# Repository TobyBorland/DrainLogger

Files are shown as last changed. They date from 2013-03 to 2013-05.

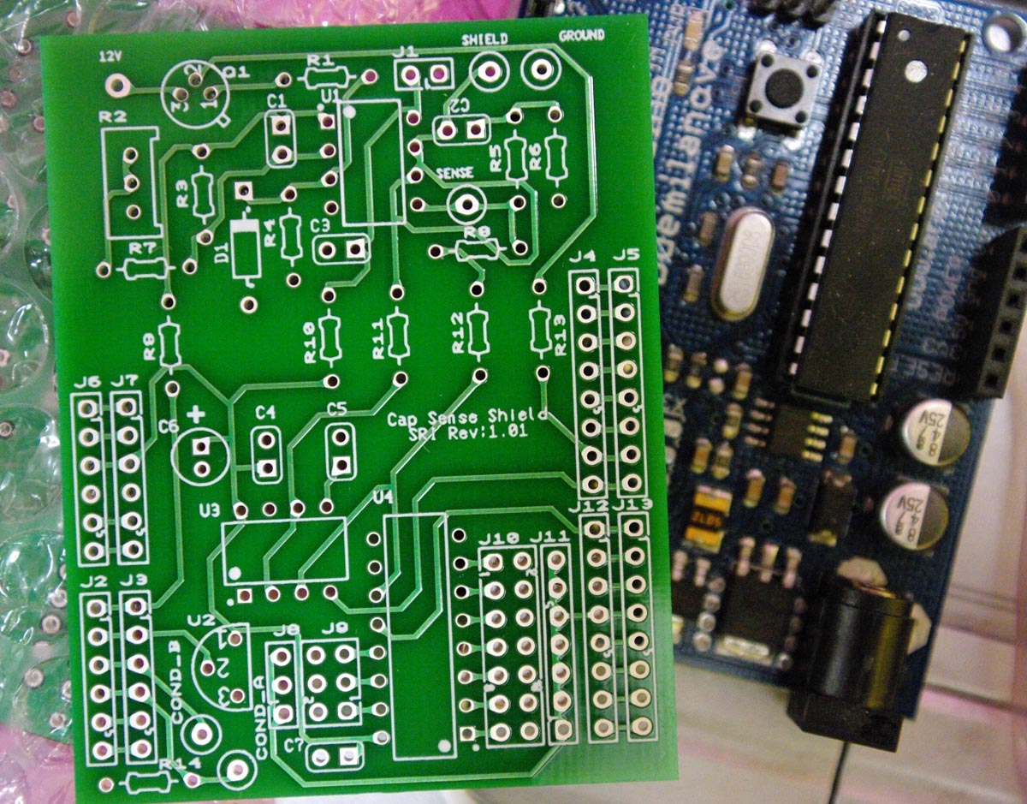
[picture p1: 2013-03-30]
Cap_Shield_07_Gerber_RS274X/Cap_Shield_07.jpg

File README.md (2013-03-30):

DrainLogger
===========

Production code for capacitance based water level sensing on Arduino platform FEB2013

The circuit uses a LadyAda SD/RTC board and a custom high sensitivity capacitance sensing board (Cap_Shield_07*.*)
Included are Gerber design files for a Solar power regulator that float charges a SLA 1500mAh battery and supplies power to the circuit (Solar_SLA_PSU_02*.*).
The Arduino circuit has been redeveloped for micro-power consumption, the shields are switched off via a power MOSFET and the processor set to hibernate.
The MOSFET is driven by a totem pole NPN/PNP switch, a Xino Arduino clone board with prototyping space is used.

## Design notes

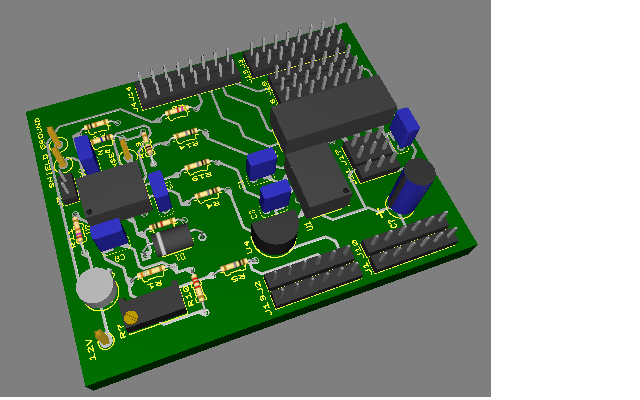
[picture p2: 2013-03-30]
Cap_Shield_07_Gerber_RS274X/3D capshield NOV12.bmp

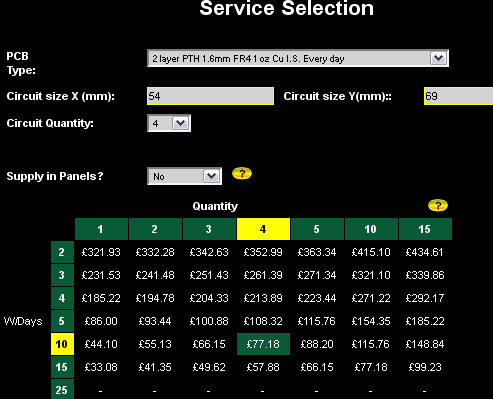
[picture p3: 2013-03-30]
Cap_Shield_07_Gerber_RS274X/PCB_train_Cap_Shield.png

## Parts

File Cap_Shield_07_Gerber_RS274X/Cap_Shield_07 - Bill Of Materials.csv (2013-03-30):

Ultiboard Information Export File
Design Name : Cap_Shield_07 - Bill Of Materials
Report Date : 15 November 2012
Report Time : 23:11
--------------------------------------------------------------------------------
VALUE | SHAPE | # | REFDES | DEVICE
0.01uF | CAPR250-500X250X550 | 1 | C5 | CAPACITOR_VIRTUAL
0.1uF | CAPR250-500X250X550 | 4 | C2,C3,C4,C7 | CAPACITOR_VIRTUAL
0.1Ohm | R0204R7_5 | 4 | R9,R10,R11,R12 | RESISTOR_VIRTUAL
1MOhm | R0204R7_5 | 1 | R8 | RESISTOR_VIRTUAL
1N5248B | DO-35 | 1 | D1 | 1N5248B
1kOhm | R0204R7_5 | 1 | R4 | RESISTOR_VIRTUAL
2N2222A | TO18 | 1 | Q1 | 2N2222A
4.7kOhm | R0204R7_5 | 1 | R13 | RESISTOR_VIRTUAL
4.7nF | CAPR250-500X250X550 | 1 | C1 | CAPACITOR_VIRTUAL
10MOhm | R0204R7_5 | 1 | R5 | RESISTOR_VIRTUAL
10kOhm | R0204R7_5 | 2 | R6,R14 | RESISTOR_VIRTUAL
20kOhm | TRIM-3386W | 1 | R2 | POTENTIOMETER_VIRTUAL
27kOhm | R0204R7_5 | 1 | R1 | RESISTOR_VIRTUAL
39kOhm | R0204R7_5 | 1 | R3 | RESISTOR_VIRTUAL
47uF | CAPPR200-500X1100 | 1 | C6 | CAP_ELECTROLIT_VIRTUAL
2200Ohm | R0204R7_5 | 1 | R7 | RESISTOR_VIRTUAL
4060BD_5V | DIP16300 | 1 | U4 | 4060BD_5V
HDR1X2 | HDR1X2 | 1 | J1 | HDR1X2
HDR1X3 | HDR1X3 | 1 | J8 | HDR1X3
HDR1X6 | HDR1X6 | 4 | J2,J3,J6,J7 | HDR1X6
HDR1X7 | HDR1X7 | 1 | J11 | HDR1X7
HDR1X8 | HDR1X8 | 4 | J4,J5,J12,J13 | HDR1X8
HDR2X3 | HDR2X3 | 1 | J9 | HDR2X3
HDR2X7 | HDR2X7 | 1 | J10 | HDR2X7
LMC555CH | DIP8300 | 1 | U3 | LMC555CH
LMC6482 | DIP8300 | 1 | U1 | LMC6482
TEST_PT1 | PB | 5 | COND_A,COND_B,GROUND,SENSE,SHIELD | TEST_PT1
TEST_PT2 | PIN | 1 | 12V | TEST_PT2
TMP36 | TO5 | 1 | U2 | TMP36

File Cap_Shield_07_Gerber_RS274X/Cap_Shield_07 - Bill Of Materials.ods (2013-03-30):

Ultiboard Information Export File
Design Name : Cap_Shield_07 - Bill Of Materials
Report Date : 15 November 2012
Report Time : 23:11
--------------------------------------------------------------------------------
VALUE | SHAPE | # | REFDES | DEVICE | Manufacturer | Manufacturer Reference | RS Stock | Price less VAT | Toby Price less VAT | Min quantity | Min required | Order Requirement | Toby sum price | Sum price | Non RS notes
0.01uF | CAPR250-500X250X550 | 1 | C5 | CAPACITOR_VIRTUAL | Murata (http://uk.rs-online.com/web/c/?searchTerm=Murata&searchType=Brand) | RPER72A103K2M1A03A | 653-0260 | £0.25 | £0.20 | 25 | 4 | 25 | £6.35 | £5.08
0.1uF | CAPR250-500X250X550 | 4 | C2,C3,C4,C7 | CAPACITOR_VIRTUAL | Murata (http://uk.rs-online.com/web/c/?searchTerm=Murata&searchType=Brand) | RPEF51H104Z2M1A03A | 721-5240 | £0.06 | £0.05 | 50 | 16 | 50 | £3.15 | £2.50
0.1Ohm | R0204R7_5 | 4 | R9,R10,R11,R12 | RESISTOR_VIRTUAL |  |  |  |  |  |  | 0 | 0 | 0 | 0
1MOhm | R0204R7_5 | 1 | R8 | RESISTOR_VIRTUAL | Arcol (http://uk.rs-online.com/web/c/?searchTerm=Arcol&searchType=Brand) | MRA02071MBTA015 | 487-8813 | £0.84 | £0.67 | 5 | 4 | 5 | £3.37 | £3.37
ZENER | DO-35 | 1 | D1 | 5.1v Zener Diode | ON Semiconductor (http://uk.rs-online.com/web/c/?searchTerm=ON+Semiconductor&searchType=Brand) | 1N5338BRLG | 625-6451 | £0.25 | £0.20 | 5 | 4 | 5 | £1.00 | £1.00
1kOhm | R0204R7_5 | 1 | R4 | RESISTOR_VIRTUAL | RS (http://uk.rs-online.com/web/c/?searchTerm=RS&searchType=Brand) |  | 707-7666 | £0.02 | £0.01 | 10 | 4 | 10 | £0.12 | £0.12
2N2222A | TO18 | 1 | Q1 | 2N2222A | Magnatec (http://uk.rs-online.com/web/c/?searchTerm=Magnatec&searchType=Brand) | 2N2222A | 295-028 | £0.58 | £0.46 | 5 | 4 | 5 | £2.32 | £2.32
4.7kOhm | R0204R7_5 | 1 | R13 | RESISTOR_VIRTUAL | RS (http://uk.rs-online.com/web/c/?searchTerm=RS&searchType=Brand) |  | 707-7726 | £0.02 | £0.01 | 10 | 4 | 10 | £0.15 | £0.12
4.7nF | CAPR250-500X250X550 | 1 | C1 | CAPACITOR_VIRTUAL | Murata (http://uk.rs-online.com/web/c/?searchTerm=Murata&searchType=Brand) | RDER72E472K2K1A11B | 749-2181 | £0.23 | £0.18 | 5 | 4 | 5 | £1.15 | £0.92
10MOhm | R0204R7_5 | 1 | R5 | RESISTOR_VIRTUAL | TE Connectivity (http://uk.rs-online.com/web/c/?searchTerm=TE+Connectivity&searchType=Brand) | CFR25J10M | 135-667 | £0.02 | £0.01 | 10 | 4 | 10 | £0.18 | £0.14
10kOhm | R0204R7_5 | 2 | R6,R14 | RESISTOR_VIRTUAL | RS (http://uk.rs-online.com/web/c/?searchTerm=RS&searchType=Brand) |  | 707-7745 | £0.01 | £0.01 | 10 | 4 | 10 | £0.09 | £0.09
20kOhm | TRIM-3386W | 1 | R2 | POTENTIOMETER_VIRTUAL | Bourns (http://uk.rs-online.com/web/c/?searchTerm=Bourns&searchType=Brand) | 3299W-1-203LF | 522-0350 | £1.39 | £1.11 | 1 | 4 | 4 | £5.56 | £4.45
27kOhm | R0204R7_5 | 1 | R1 | RESISTOR_VIRTUAL | RS (http://uk.rs-online.com/web/c/?searchTerm=RS&searchType=Brand) |  | 707-7782 | £0.01 | £0.01 | 10 | 4 | 10 | £0.11 | £0.09
39kOhm | R0204R7_5 | 1 | R3 | RESISTOR_VIRTUAL | RS (http://uk.rs-online.com/web/c/?searchTerm=RS&searchType=Brand) |  | 707-7791 | £0.01 | £0.01 | 10 | 4 | 10 | £0.11 | £0.09
47uF | CAPPR200-500X1100 | 1 | C6 | CAP_ELECTROLIT_VIRTUAL | RS (http://uk.rs-online.com/web/c/?searchTerm=RS&searchType=Brand) |  | 711-1444 | £0.04 | £0.04 | 50 | 4 | 50 | £1.75 | £1.75
2200Ohm | R0204R7_5 | 1 | R7 | RESISTOR_VIRTUAL | RS (http://uk.rs-online.com/web/c/?searchTerm=RS&searchType=Brand) |  | 707-7690 | £0.02 | £0.01 | 10 | 4 | 10 | £0.15 | £0.12
4060BD_5V | DIP16300 | 1 | U4 | 4060BD_5V | STMicroelectronics (http://uk.rs-online.com/web/c/?searchTerm=STMicroelectronics&searchType=Brand) | HCF4060BEY | 714-0562P | £0.16 | £0.14 | 20 | 0 | 20 | £2.78 | £2.78
HDR1X2 | HDR1X2 | 1 | J1 | HDR1X2 |  |  |  |  |  |  |  | 0 | 0 | 0
HDR1X3 | HDR1X3 | 1 | J8 | HDR1X3 |  |  |  |  |  |  |  | 0 | 0 | 0
HDR1X6 | HDR1X6 | 2 | J2,J3,J6,J7 | HDR1X6 |  |  |  |  |  |  |  | 0 | 0 | 0
HDR1X7 | HDR1X7 | 1 | J11 | HDR1X7 |  |  |  |  |  |  |  | 0 | 0 | 0
HDR1X8 | HDR1X8 | 2 | J4,J5,J12,J13 | HDR1X8 |  |  |  |  |  |  |  | 0 | 0 | 0
HDR2X3 | HDR2X3 | 1 | J9 | HDR2X3 |  |  |  |  |  |  |  | 0 | 0 | 0
HDR2X7 | HDR2X7 | 1 | J10 | HDR2X7 |  |  |  |  |  |  |  | 0 | 0 | 0
LMC555CH | DIP8300 | 1 | U3 | LMC555CH | Texas Instruments (http://uk.rs-online.com/web/c/?searchTerm=Texas+Instruments&searchType=Brand) | LMC555CN/NOPB | 534-4002 | £0.85 | £0.68 | 1 | 4 | 4 | £2.72 | £3.40
LMC6482 | DIP8300 | 1 | U1 | LMC6482 | Texas Instruments (http://uk.rs-online.com/web/c/?searchTerm=Texas+Instruments&searchType=Brand) | LMC6482AIN/NOPB | 536-0183 | £1.56 | £1.25 | 5 | 4 | 5 | £6.23 | £7.78
TEST_PT1 | PB | 5 | COND_A,COND_B,GROUND,SENSE,SHIELD | TEST_PT1 |  |  |  |  |  |  |  | 0 | 0 | 0
TEST_PT2 | PIN | 1 | 12V | TEST_PT2 |  |  |  |  |  |  |  | 0 | 0 | 0
TMP36 | TO5 | 1 | U2 | TMP36 | Analog Devices (http://uk.rs-online.com/web/c/?searchTerm=Analog+Devices&searchType=Brand) | TMP36GT9Z | 427-351 | £1.39 | £1.11 | 5 | 4 | 5 | £5.56 | £6.95
 |  |  |  |  |  |  |  |  |  |  |  | 0 | 0 | 0
Socket strip | HDR1x6 | 2 |  |  | Winslow (http://uk.rs-online.com/web/c/?searchTerm=Winslow&searchType=Brand) |  | 401-699 | £1.50 | £1.20 | 5 | 8 | 10 | £15.02 | £12.02
Socket strip | HDR1x8 | 2 |  |  | Winslow (http://uk.rs-online.com/web/c/?searchTerm=Winslow&searchType=Brand) |  |  |  |  |  |  | 0 | 0 | 0
Silicone conformal coating |  |  |  |  | RS (http://uk.rs-online.com/web/c/?searchTerm=RS&searchType=Brand) |  | 494-714 | £9.02 | £7.22 | 1 | 1 | 1 | £9.02 | £7.22
Flux remover |  |  |  |  | ITW Chemtronics (http://uk.rs-online.com/web/c/?searchTerm=ITW+Chemtronics&searchType=Brand) | ES830BE | 298-7937 | £7.64 | £6.11 | 1 | 1 | 1 | £7.64 | £6.11
Board rinse |  |  |  |  | RS (http://uk.rs-online.com/web/c/?searchTerm=RS&searchType=Brand) |  | 497-016 | £6.90 | £5.52 | 1 | 1 | 1 | £6.90 | £5.52
 |  |  |  |  |  |  |  |  |  |  |  | 0 | 0 | 0
CoAx cable |  |  |  |  |  | Cricklewood | ZS1 | £0.40 |  | 1 | 4 | 4 | £1.60 | 0 | http://www.cricklewoodelectronics.com/Cricklewood/product.php?productid=18957&cat=326&page=1
 |  |  |  |  |  |  |  |  |  |  |  | 0 | 0 | 0
INA125PA | DIP16300 | 1 | U47 | OP_AMP | Texas Instruments (http://uk.rs-online.com/web/c/?searchTerm=Texas+Instruments&searchType=Brand) | INA125PA | 252-1593 | £4.39 | £3.51 | 1 | 2 | 2 | £7.02 | £8.78
Optocoupler | DIP8300 | 1 | U39 | ACPL-827-000E | Avago Technologies (http://uk.rs-online.com/web/c/?searchTerm=Avago+Technologies&searchType=Brand) | ACPL-827-000E | 693-5937 | £0.63 | £0.50 | 1 | 2 | 2 | £1.26 | £1.01
Piezodisc |  |  |  |  | RS (http://uk.rs-online.com/web/c/?searchTerm=RS&searchType=Brand) |  | 724-3162 | £0.34 | £0.27 | 5 | 1 | 5 | £1.70 | £1.36
Optocoupler | DIP8300 | 1 | U39a | H11A1X | Isocom (http://uk.rs-online.com/web/c/?searchTerm=Isocom&searchType=Brand) | H11A1X | 111-122 | £0.49 | £0.39 | 1 | 1 | 1 | £0.49 | £0.39
 |  |  |  |  |  |  |  |  |  |  |  | 0 | 0 | 0
 |  |  |  |  |  |  |  |  |  |  |  | 0 | 0 | 0
 |  |  |  |  |  |  |  |  |  |  |  | 0 | 0 | 0
Ultiboard Information Export File |  |  |  |  |  |  |  |  |  |  |  | 0 | 0 | 0
 |  |  |  |  |  |  |  |  |  |  |  | 0 | 0 | 0
Design Name : drainlogger_PSU(drainlogger_PSU) - Bill Of Materials |  |  |  |  |  |  |  |  |  |  |  | 0 | 0 | 0
Report Date : 16 November 2012 |  |  |  |  |  |  |  |  |  |  |  | 0 | 0 | 0
Report Time : 01:05 |  |  |  |  |  |  |  |  |  |  |  | 0 | 0 | 0
-------------------------------------------------------------------------------- |  |  |  |  |  |  |  |  |  |  |  | 0 | 0 | 0
 |  |  |  |  |  |  |  |  |  |  |  | 0 | 0 | 0
VALUE | SHAPE | # | REFDES | DEVICE |  |  |  |  |  |  |  | 0 | 0 | 0
 |  |  |  |  |  |  |  |  |  |  |  | 0 | 0 | 0
0.27Ohm | RES12 | 1 | R3 | RESISTOR_VIRTUAL |  |  | N/A |  |  |  |  | 0 | 0 | 0
0.68Ohm | RES12 | 1 | R2 | RESISTOR_VIRTUAL |  |  | N/A |  |  |  |  | 0 | 0 | 0
1.5kOhm | R0204R7_5 | 1 | R7 | RESISTOR_VIRTUAL | RS (http://uk.rs-online.com/web/c/?searchTerm=RS&searchType=Brand) |  | 707-7681 | £0.02 | £0.01 | 10 | 4 | 10 | £0.15 | £0.12
1N5818 | DO-41 | 1 | D1 | 1N5818/9 | ON Semiconductor (http://uk.rs-online.com/web/c/?searchTerm=ON+Semiconductor&searchType=Brand) | 1N5818RLG | 625-5212 | £0.46 | £0.37 | 1 | 4 | 4 | £1.84 | £1.47
1Ohm | RES12 | 1 | R1 | RESISTOR_VIRTUAL | RS (http://uk.rs-online.com/web/c/?searchTerm=RS&searchType=Brand) |  | 707-7981 | £0.03 | £0.02 | 10 | 4 | 10 | £0.27 | £0.22
4.7kOhm | NTC_K164 | 1 | R4 | RESISTOR_VIRTUAL | BC Components (http://uk.rs-online.com/web/c/?searchTerm=BC+Components&searchType=Brand) | 238164066473 | 538-0749 | £0.61 | £0.49 | 1 | 4 | 4 | £2.42 | £1.94 | Maplin:FX21X
200mA | PTC_B77 | 1 | R8 | RESETTABLE FUSE | TE Connectivity (http://uk.rs-online.com/web/c/?searchTerm=TE+Connectivity&searchType=Brand) | RXEF010 | 517-6562 | £0.31 | £0.25 | 10 | 4 | 10 | £3.10 | £2.48
10kOhm | TRIM-3386W | 1 | R6 | POTENTIOMETER_VIRTUAL | Murata (http://uk.rs-online.com/web/c/?searchTerm=Murata&searchType=Brand) | PV36X103C01B00 | 725-0325 | £0.95 | £0.76 | 1 | 4 | 4 | £3.80 | £3.04
10nF | CAPR250-500X250X550 | 1 | C1 | CAPACITOR_VIRTUAL | Murata (http://uk.rs-online.com/web/c/?searchTerm=Murata&searchType=Brand) | RPER72A103K2M1A03A | 653-0260 | £0.25 | £0.20 | 25 | 4 | 25 | £5.08 | £6.35
100uF | CAPR250-500X250X550 | 2 | C2,C3 | CAPACITOR_VIRTUAL | Vishay (http://uk.rs-online.com/web/c/?searchTerm=Vishay&searchType=Brand) | MAL203851101E3 | 684-2018 | £0.12 | £0.09 | 5 | 8 | 10 | £1.16 | £0.93
100Ohm | R0204R7_5 | 1 | R5 | RESISTOR_VIRTUAL | RS (http://uk.rs-online.com/web/c/?searchTerm=RS&searchType=Brand) |  | 707-7587 | £0.02 | £0.01 | 10 | 4 | 10 | £0.15 | £0.12
2200uF | CAPPR750-1800X3550 | 1 | C4 | CAP_ELECTROLIT_VIRTUAL | Vishay (http://uk.rs-online.com/web/c/?searchTerm=Vishay&searchType=Brand) | MAL203850222E3 | 684-1992 | £0.78 | £0.63 | 5 | 4 | 5 | £3.91 | £3.13
HDR1X2 | SMK2R5MIL_A | 3 | J1,J2,J3 | HDR1X2 | Phoenix Contact (http://uk.rs-online.com/web/c/?searchTerm=Phoenix+Contact&searchType=Brand) | SMKDSN 1,5/ 2-5,08 | 206-4595 | £0.48 | £0.38 | 5 | 12 | 15 | £7.20 | £5.76
5V DC-DC | TRIM-3299W | 1 | U1 | R-785.0-0.5 | Recom (http://uk.rs-online.com/web/c/?searchTerm=Recom&searchType=Brand) | R-785.0-0.5 | 532-8050P | £5.48 | £4.66 | 1 | 4 | 4 | £21.92 | £18.63
L200CV | TO-220(TO5B) | 1 | L200C1 | Pentawatt | STMicroelectronics | Cricklewood | N/A | £1.50 | £1.50 | 1 | 4 | 4 | £6.00 | £6.00
Heatsink |  |  |  |  | AAVID THERMALLOY (http://uk.rs-online.com/web/c/?searchTerm=AAVID+THERMALLOY&searchType=Brand) | 574502B00000G | 712-4197 | £0.27 | £0.22 | 5 | 4 | 5 | £1.35 | £1.08
1.6Ohm (+nichrome link) | 0.5W |  | R1, R2, R2 |  | RS (http://uk.rs-online.com/web/c/?searchTerm=RS&searchType=Brand) |  | 707-8003 | £0.02 | £0.02 | 10 | 4 | 10 | £0.20 | £0.16
Battery cable |  |  |  |  |  | Cricklewood | ZL27H | £19.00 | £19.00 | 1 | 1 | 1 | £19.00 | £19.00 | http://www.cricklewoodelectronics.com/Cricklewood/product.php?productid=18931&cat=322&page=1
Spade Connectors |  |  |  |  | JST (http://uk.rs-online.com/web/c/?searchTerm=JST&searchType=Brand) | 4803-187 | 688-1022 | £0.02 | £0.02 | 100 | 8 | 100 | £2.30 | £1.80
Batterybox |  |  |  |  | Gunther Spelsberg (http://uk.rs-online.com/web/c/?searchTerm=Gunther+Spelsberg&searchType=Brand) | 11040401 | 220-428 | £6.65 | £5.32 | 1 | 4 | 4 | £26.60 | £21.28
Battery box grommet |  |  |  |  | RS (http://uk.rs-online.com/web/c/?searchTerm=RS&searchType=Brand) |  | 444-2616 | £0.51 | £0.41 | 5 | 4 | 5 | £2.56 | £2.05
12V Battery |  |  |  |  | Yuasa (http://uk.rs-online.com/web/c/?searchTerm=Yuasa&searchType=Brand) | Y 1.2-12 FR | 614-1905 | £9.56 | £7.65 | 1 | 4 | 4 | £38.24 | £30.59
 |  |  |  |  |  |  |  |  |  |  |  |  | £240.75 | £211.63
TOTAL+VAT |  |  |  |  |  |  |  |  |  |  |  |  | £288.90 | £253.95

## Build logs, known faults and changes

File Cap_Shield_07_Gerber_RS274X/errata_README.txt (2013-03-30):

Errors and addendums in production board:

1: U2 silkscreen is reversed, temperature sensor faces other way around
2: Battery sense circuit revised to NPN/PNP totem switch

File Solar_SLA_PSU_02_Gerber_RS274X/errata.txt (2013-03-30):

1N456A diode replaced with low leakage diode

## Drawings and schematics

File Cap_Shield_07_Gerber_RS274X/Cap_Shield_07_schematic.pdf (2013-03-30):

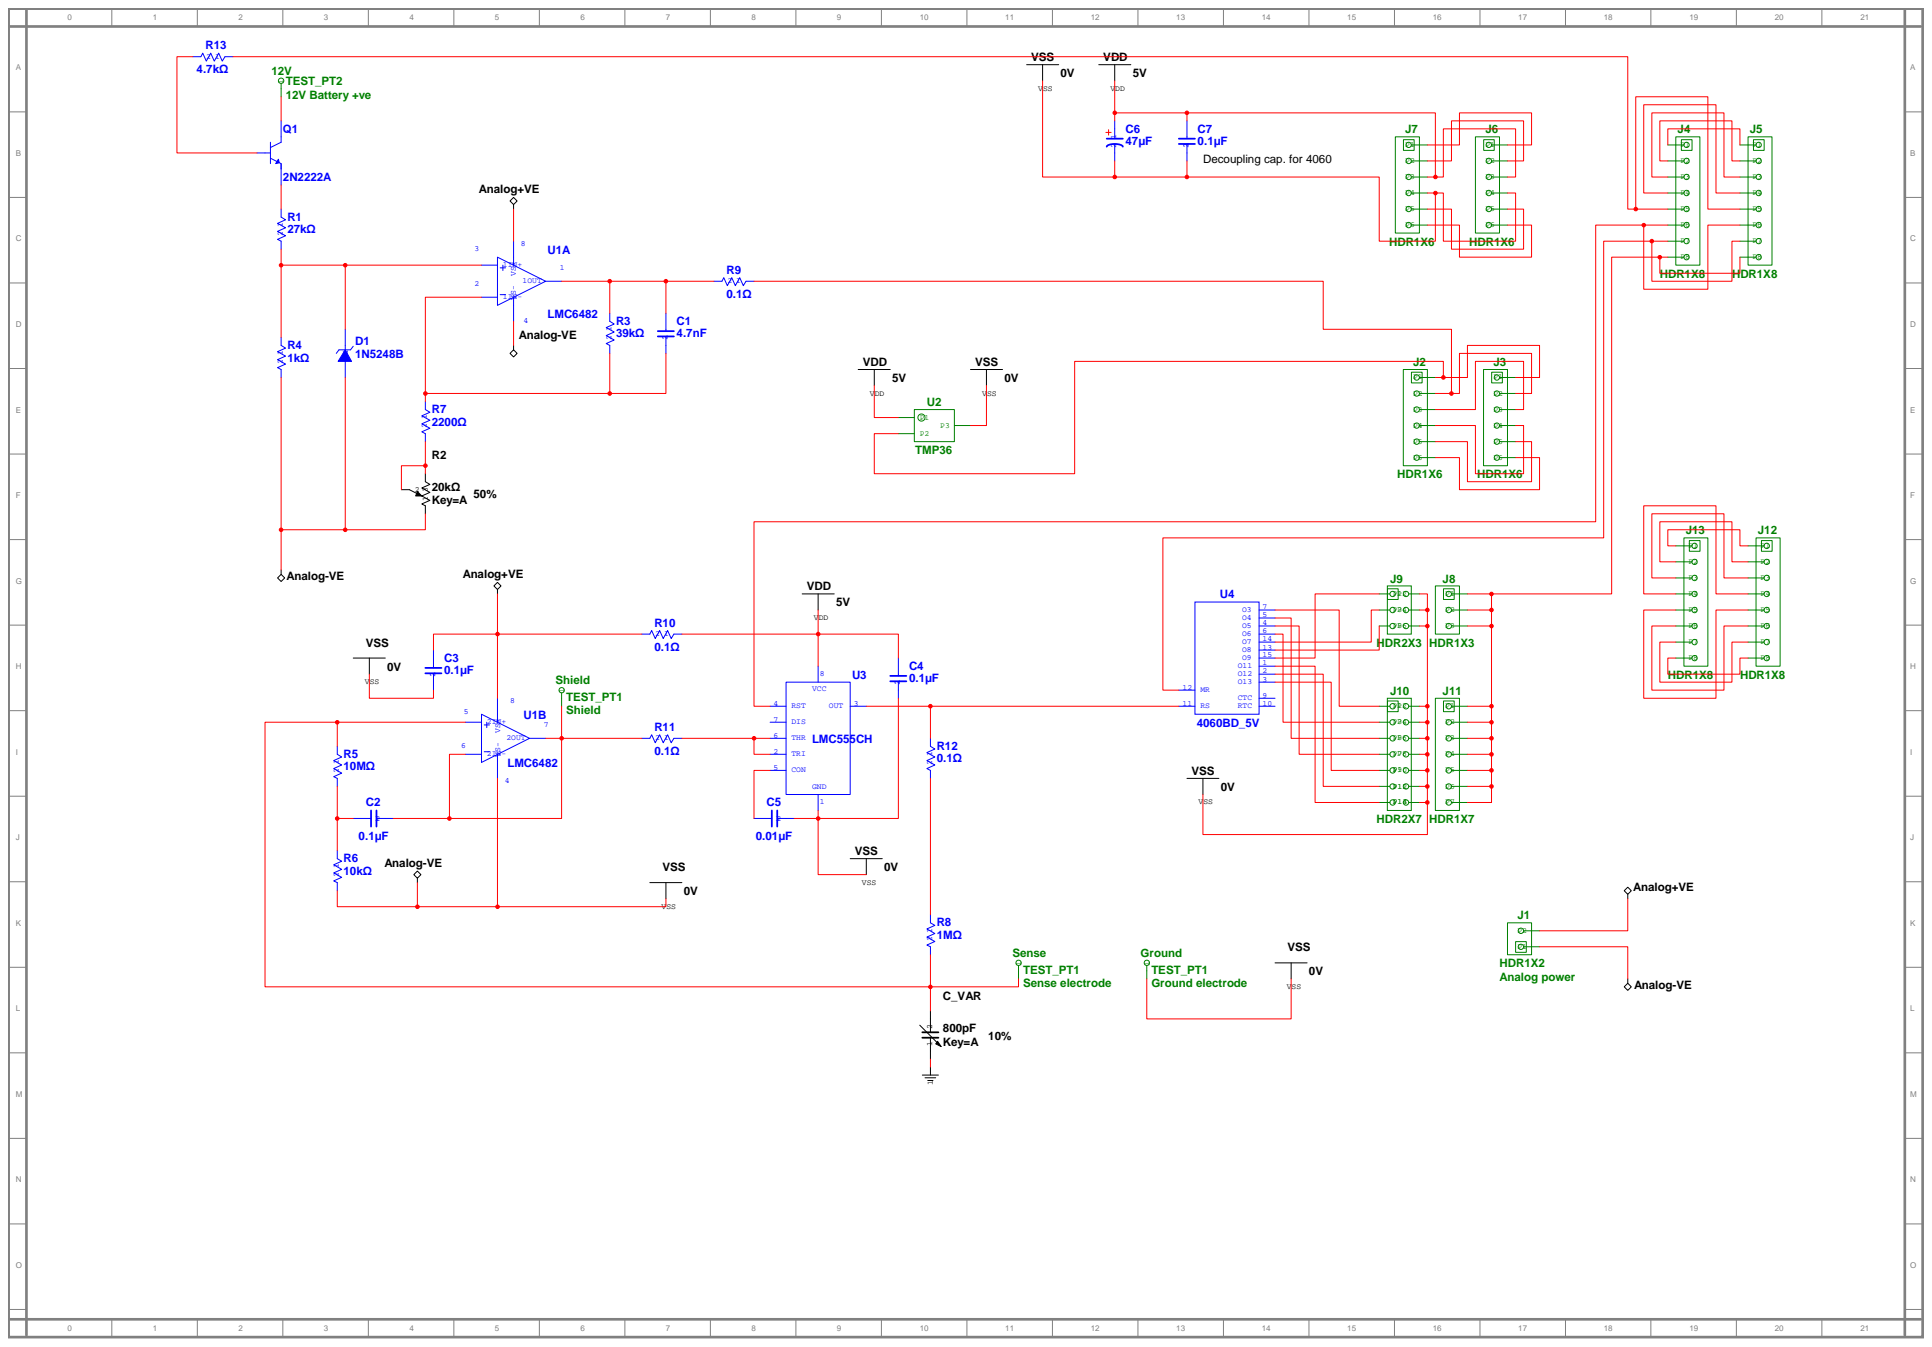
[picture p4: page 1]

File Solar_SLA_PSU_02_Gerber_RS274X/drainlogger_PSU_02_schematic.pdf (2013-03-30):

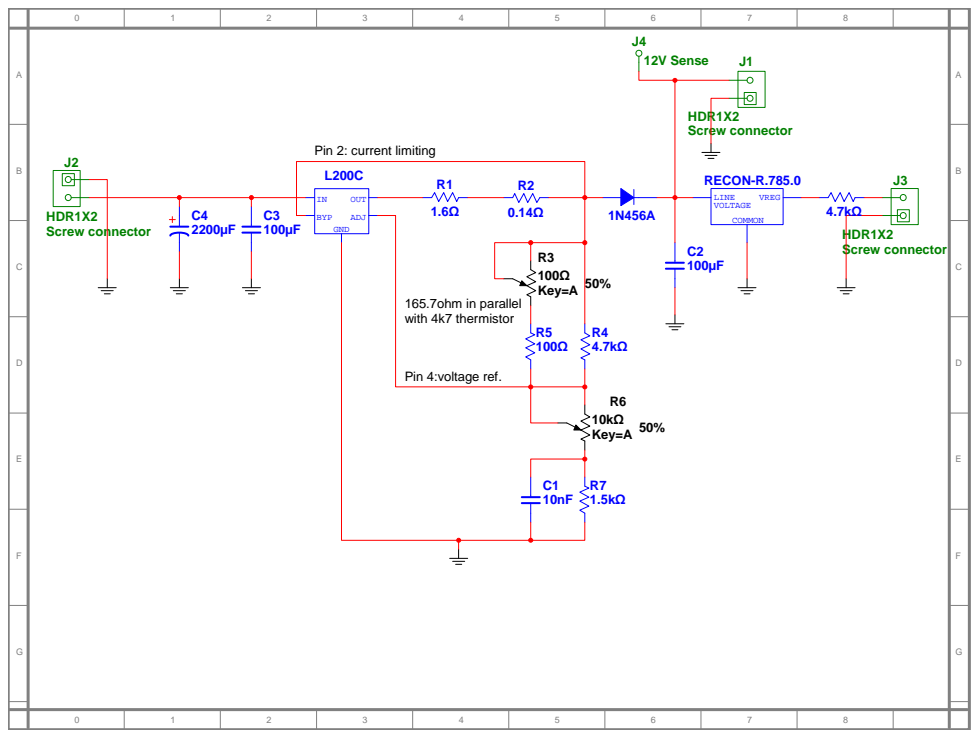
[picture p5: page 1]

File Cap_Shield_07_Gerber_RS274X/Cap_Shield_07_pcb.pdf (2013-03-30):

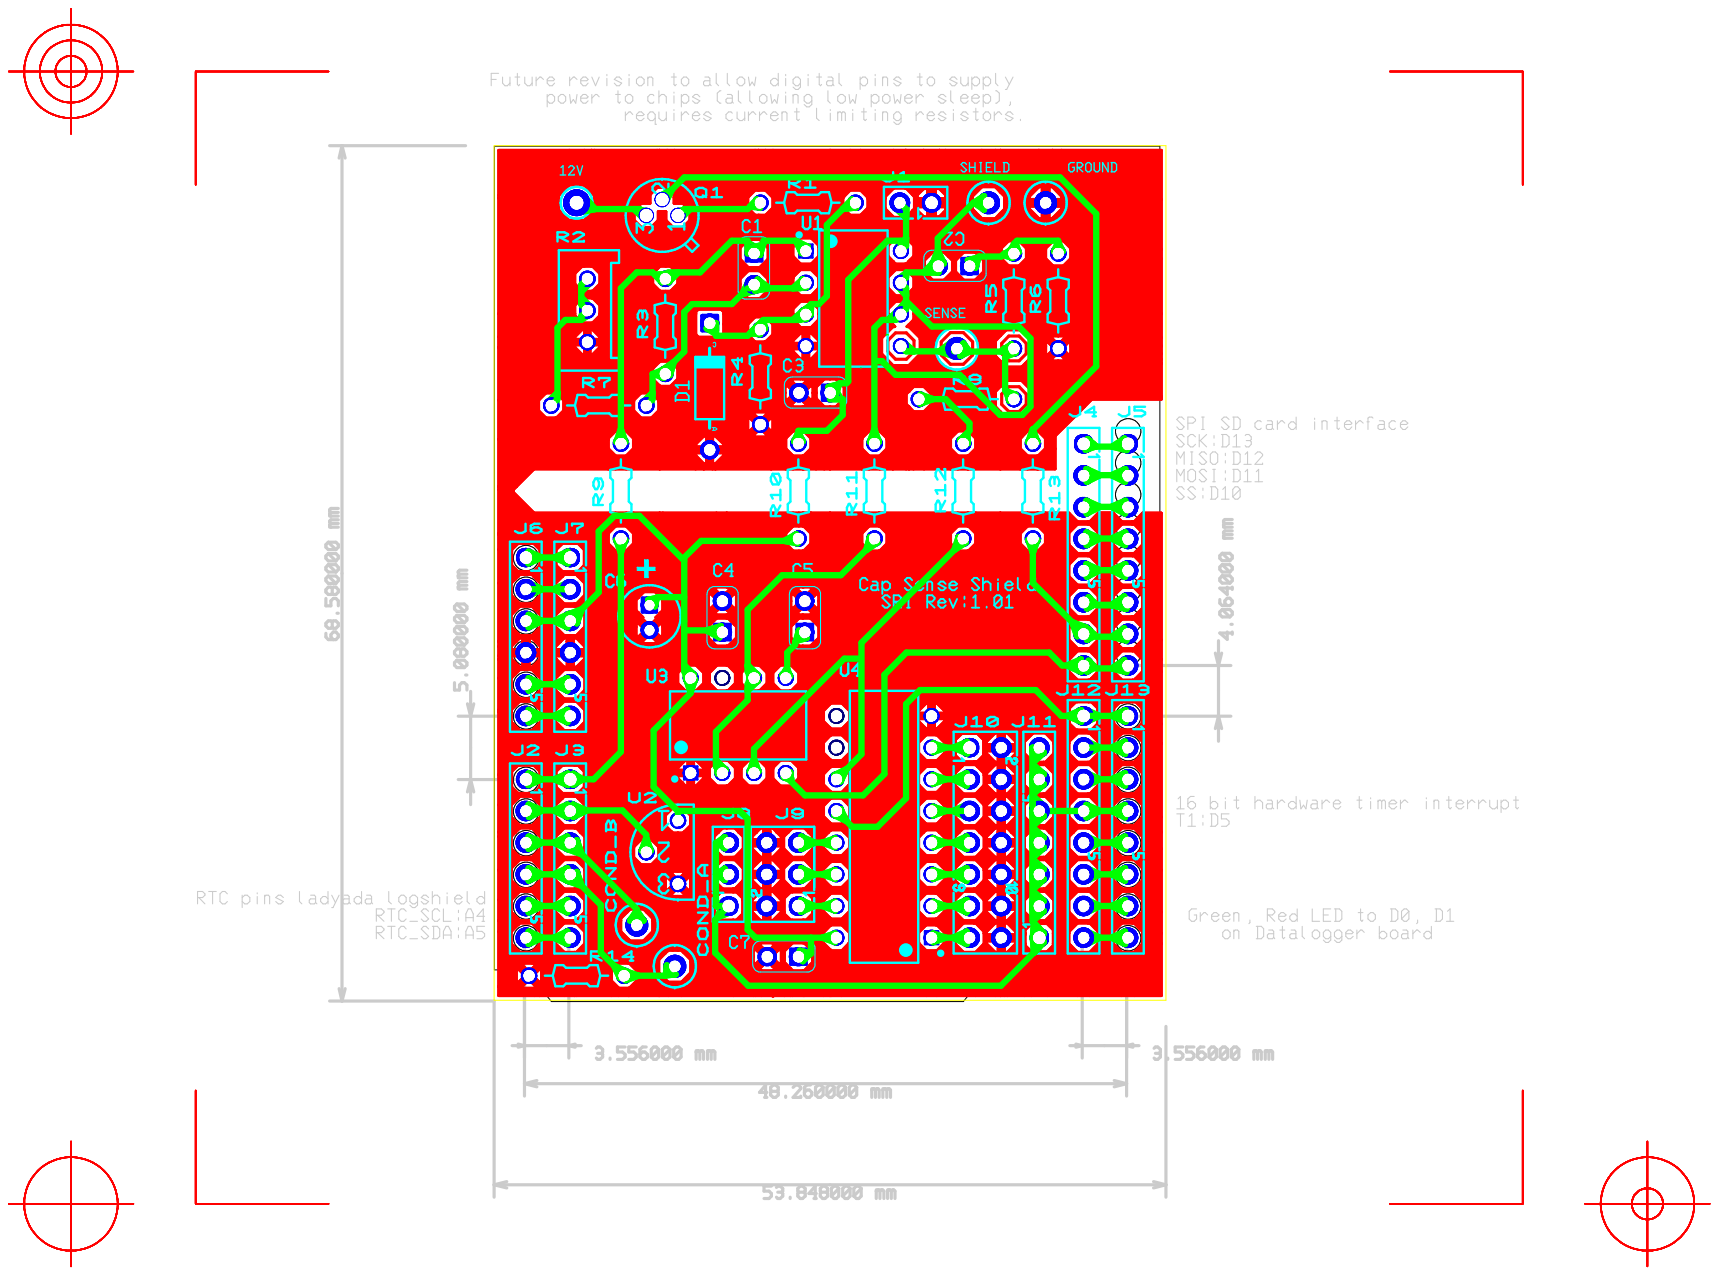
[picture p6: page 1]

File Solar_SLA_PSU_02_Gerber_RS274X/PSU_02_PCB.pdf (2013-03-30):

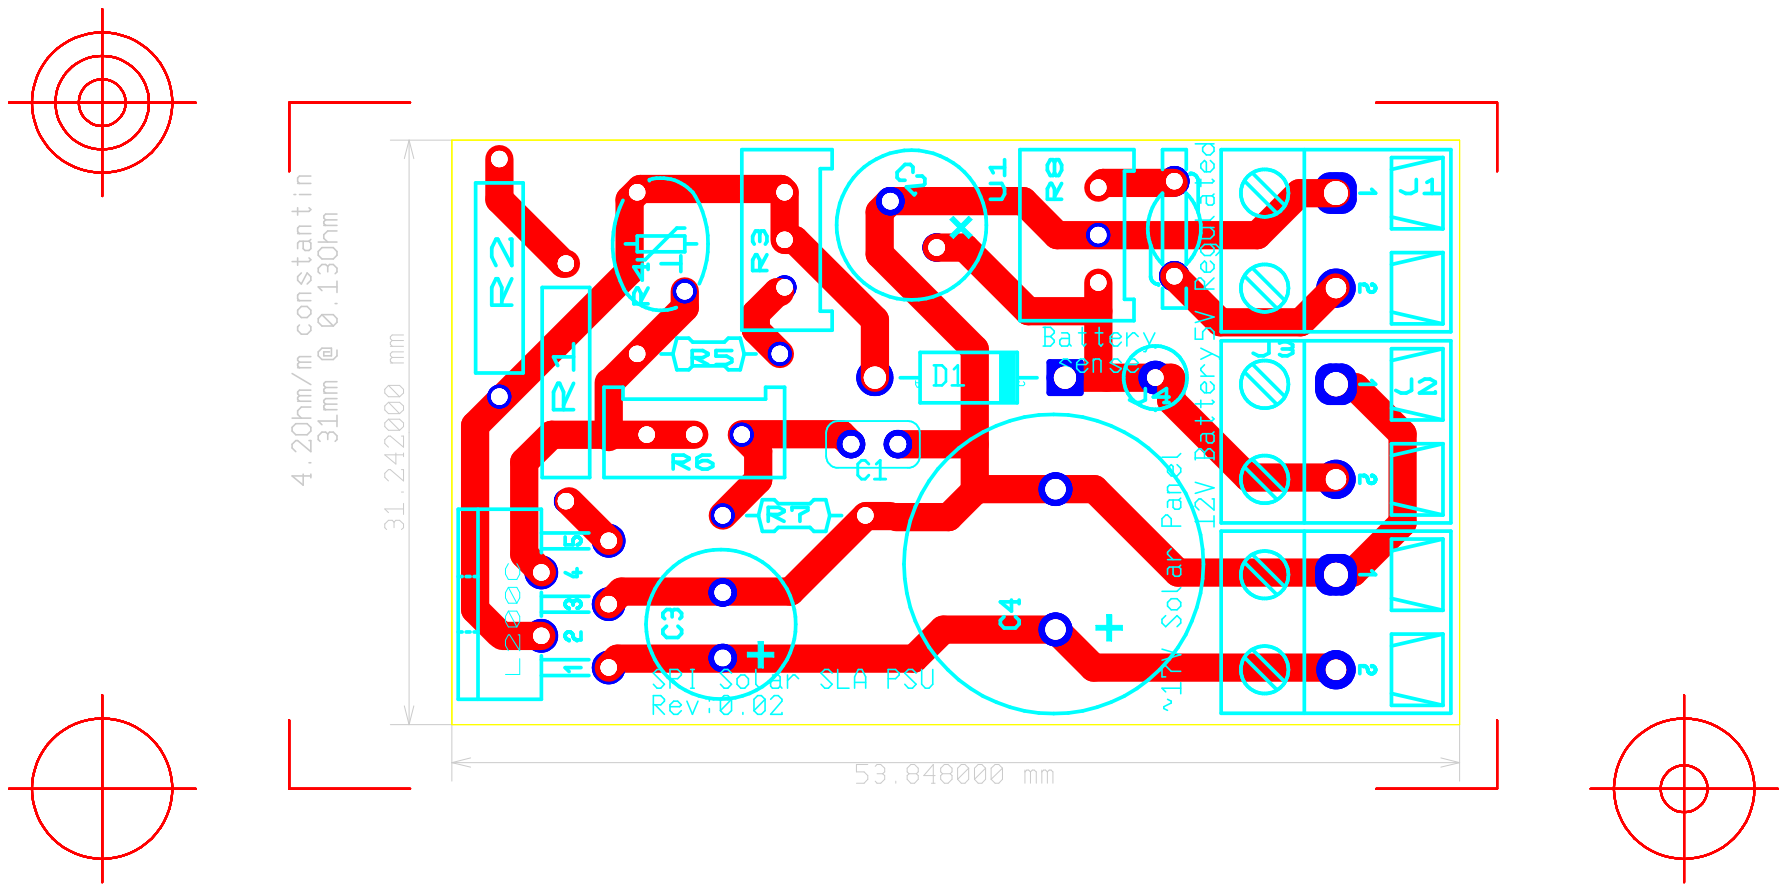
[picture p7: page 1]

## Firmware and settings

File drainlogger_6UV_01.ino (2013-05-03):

/*
drainlogger.ino is the program operating a capacitive water level sensing
hardware design developed at the Sustainability Institute at the University 
of East London. 

Copyright Toby Borland 2012-2013

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
    You should have received a copy of the GNU General Public License
    along with this program.  If not, see <http://www.gnu.org/licenses/>.
*/

// Arduino drainlogger 0.0.6UV - V-notch/Uno variant
// Sustainability Research Institute, University of East London
// Toby Borland with contribution from Ertion Axha, Gertz, DeJusto
// tobyborland@hotmail.com
// XINO SERIAL 9600 BAUD OVER DUEMILANOVE BOARD OK
// Xino => set board type to Arduino Uno
#define SENSOR_IDENTIFIER "Unit:            0000"

// Hazen-Williams friction head loss empirical formula: f = (10.67*(100/c)^1.85*q^1.85)*D_h^-4.87 (SI units)
// f = friction head, c = Hazen-Williams roughness constant, q = volume flow, D_h = inside hydraulic diameter
// pipe of roughness factor 150 and 5m vertical drop
// 160mm dia pipe => 0.337 m^3/s discharge rate & velocity of 16.7 m/s
// 125mm dia pipe => 0.176 m^3/s discharge rate & 14.3 m/s velocity

#include <avr/wdt.h> // AVR watchdog timer
#include <avr/sleep.h>

#include <I2cMaster.h>
#include <SoftRTClib.h>

#include <SdFat.h>
#include <SdFatUtil.h> // use Serial.print

// Olimex-32U4 Leonardo architecture issues:
// Serial.read requires XP SP3 updates (Jan2012)

// use Software SPI edit SdFatConfig.h at about line 121 of Dec2012 SdFat
// #define LEONARDO_SOFT_SPI 1

#if defined(__AVR_ATmega32U4__)
#if !LEONARDO_SOFT_SPI
#error set LEONARDO_SOFT_SPI nonzero in libraries/SdFat/SdFatConfig.h
#endif  // LEONARDO_SOFT_SPI
// Is a Leonardo use analog pins 4, 5 for software I2C
const uint8_t RTC_SCL_PIN = 23;
const uint8_t RTC_SDA_PIN = 22;
SoftI2cMaster i2c(RTC_SDA_PIN, RTC_SCL_PIN);

#else  // defined(__AVR_ATmega1280__) || defined(__AVR_ATmega2560__)
// Not Mega use hardware I2C
// enable pull-ups on SDA/SCL
TwiMaster i2c(true);
#endif  // defined(__AVR_ATmega1280__) || defined(__AVR_ATmega2560__)

// RTC pins commandeered on ladyada logshield
// RTC_SCL - A4
// RTC_SDA - A5

// SPI pins commandeered
// SS – D10
// MOSI – D11
// MISO – D12
// SCK – D13

// ATmega48A/PA/88A/PA/168A/PA/328/P [DATASHEET] p.139
// 16 bit hardware timer interrupt T1 - D5
// NOTE pin not initialised

#define FILE_MAX_LOG  336 // max# entries per file  - tune this to SD cluster/block size of 8KB
// default cluster sizes for FAT32 under >Windows98
// 256 MB–8GB	4 KB	4 KB	4 KB
// 8GB–16GB 	8 KB	8 KB	8 KB
// 16GB–32GB 	16 KB	16 KB	16 KB
// tradeoff between data security and SD storage efficiency: assume/dictate 8KB cluster size => < 8KB file size = 340 lines of 23 char including \n.
#define FILE_CHAR_COUNT  8156  // for 8KB 23char/line 336 entry file

#define ECHO_TO_SERIAL 0  // echo data to serial port
#define SERIAL_BAUD 9600 // defined in several places
#define DEBUG 0
#define TIME_DBG 0
#define LED_ON 0 // RX, TX shared with LEDs, disable LED_ON if ECHO_TO_SERIAL
#define WDT_RESET_LIMIT 8000 // 8 second watchdog timer system reset interval (max), adjusted by order of hibernate() or initWDT() call.
#define RESOLUTION 2 // seconds pause between readings
#define SLEEP_ON 1 // also used in temperature calibration delay
#define SD_LOG 1  // 
#define SD_CHECK 0 // free clusters, time consuming
#define RTC_SYNC 0  // query PC time to reset RTC

// SRI Cap Sense Shield 1.01 pinout & Xino v1.5 revised power
const byte redLEDpin = 0; //D3 protoboard value, D2 Olimex original, D0 Xino (to prevent conflict w/ upload programming)
const byte greenLEDpin = 1; //D4 protoboard value, interferes with pulse sense pin on Cap_Sense_Shield 1.01 (shift to D3?)
const byte gateMOSFET = 2; // switch power to peripherals for low power sleep
const byte pulseSensePin = 4; //D5 on protoboard
const byte CD4060ResetPin = 7; // not present on protoboard, interferes w/ LM555 reset, D7 on Cap_Sense_Shield 1.01D7
const byte LM555ResetPin = 8; //D7 on protoboard, D8 on Cap_Sense_Shield 1.01 (OLIMEXINO LED)
const byte batteryTestEnablePin = 9; //D9 (OLIMEXINO LED)
const byte batteryVoltagePin = 14; //A0/D14
const byte TMP36pin = 15; //Analog 0 on protoboard, A1/D15 on Cap_Sense_Shield 1.01
const byte Conduct_BsensePin = 16; //A2/D16
const byte Conduct_AdrivePin = 17; //A3/D17
const byte chipSelect = 10;

// constants for conductivity testing
const float refVoltage = 5.00; // CHANGE THIS FOR 3.3v Arduinos
const float aResn = refVoltage / 1024;
const float res10K = 9850.0;

const byte WINDOW = 25; // rectangular smoothing window width, must be > 2
// eyeball smoothing dl_58LVt_window & graphing.pde => 25 optimum

unsigned int shiftIndex = WINDOW-2;
unsigned long avg_pulse[WINDOW]; // be warned of rollover issues with long delays (e.g. CD4060 divider)
unsigned long pulse, raw_pulse, ref_pulse, max_pulse, min_pulse;
volatile unsigned long WDT_catch; // always less than 8000, but requires millis() => UL
#if DEBUG
  volatile unsigned long ongoing = 0; // WDT interrupt counter, only used for DEBUG
#endif
#if TIME_DBG
  volatile unsigned long timeProfile = 0;//millis();
#endif

int signal_check;
byte i;

unsigned int JITTER = 2;//___________________________FINE_TUNE
// unsuited as an exit condition for temperature calibration?

unsigned int NO_WATER = 60; // if the meter dries out, there is stray capacitance_________CHECK VALUE
byte no_flow = 0; // global variable set if activity and pulse width below threshold -> hibernate
unsigned long min_loop = 0; // wraparound issues if set to byte
unsigned long still_no_flow = 0;

RTC_DS1307 RTC(&i2c); // define Real Time Clock object
// DS1307RTC chip battery fabled to last 5 years (www.ladyada.net)
DateTime now;

// create file object
SdFat sd;
SdFile logfile;
SdFile readfile;
Sd2Card card; // card insertion & space checking services
SdVolume vol;
cid_t cid;
unsigned long SD_serial;

// store error strings in flash to save RAM <SdFatUtil.h>
#define error(s) sd.errorHalt_P(PSTR(s))
//#define errorHalt(s) error_P(PSTR(s))

ISR (WDT_vect) { // watchdog interrupt
  // anything persistent - note volatile variable requirement
  #if LED_ON
    if (digitalRead(greenLEDpin) == HIGH) {
      digitalWrite(greenLEDpin, LOW);
    }else{
      digitalWrite(greenLEDpin, HIGH);
    } // toggle, delay doesn't work
  #endif
  #if DEBUG
    Serial.print(F("DEBUG ISR() ongoing: "));Serial.println(ongoing);
    ++ongoing;
  #endif
}
 
float getPowerVoltage(void){
  // use spare channel of op-amp to measure battery voltage input
  // data used to determine success of remote power supplies

  // switch voltage divider circuit power on 
  digitalWrite(batteryTestEnablePin, HIGH);
  delay(1000); //allow steady state level
  float V = analogRead(batteryVoltagePin);

  V = (V + 7.72)/34.1; 
  digitalWrite(batteryTestEnablePin, LOW);
  #if DEBUG
    Serial.print(F("DEBUG getPowerVoltage() V: ")); Serial.println(V);
  #endif
  return V;
}

float getTemp() {
  int reading = analogRead(TMP36pin);
  float voltage = reading * 5.0;
  voltage /= 1024.0; 
  float tempC = (voltage - 0.5) * 100 ;
  #if DEBUG
    Serial.print(F("DEBUG getTemp() tempC: ")); Serial.println(tempC);
    //Serial.print(F("DEBUG getTemp() reading: ")); Serial.println(reading);
  #endif
  return tempC;
}  // getTemp()

float getSiemens(void){
  // Environmental Monitoring with Arduino, E. Gertz & P. De Justo, O'Reilly, p.35
  // measure electrical conductivity of water.
  //int threshold = 3;
  
  // rainwater test: 160 mS
  // deionised water 78 mS
  // 100K resistor 2500 mS
  // 10.26 mm seperation between contacts.
  
  int analogV = 0;
  int ref_AnalogV = 1000;
  float V = 0.0;
  float R = 0.0;
  double Siemens;

  while((ref_AnalogV - analogV) > 3){
    ref_AnalogV = analogV;
    digitalWrite( Conduct_AdrivePin, HIGH );
    delay(10); // allow ringing to stop
    analogV = analogRead(Conduct_BsensePin);
    digitalWrite( Conduct_AdrivePin, LOW );
  }

  V = (analogV * aResn);
  R = ((5.00 * res10K) / V) - res10K;
  Siemens = 1.0/(R/1000000);

  #if DEBUG
    if (V > 4.9) Serial.println(F("DEBUG conductivity probe short?"));//____________________________recalibration fn.
    Serial.print(F("DEBUG getSiemens() V: ")); Serial.println(V);
    Serial.print(F("DEBUG getSiemens() Siemens: ")); Serial.println(Siemens);
  #endif

  return Siemens;
} //getSiemens()

#if RTC_SYNC
  void serialSynch(void){
    DateTime dt;
    if(Serial.available()){
      time_t t = processSyncMessage(); // DS1307RTC.h value
      if(t >0){
        dt.settime(t);
        RTC.setTime(&dt);   // set the RTC and the system time to the received value
        //setTime(now);          
        #if DEBUG
          Serial.print(F("DEBUG serialSynch() t: ")); Serial.println(t);
        #endif
      }
    }
  }  //serialSynch()
  
  time_t processSyncMessage(void){
    // return the time if a valid sync message is received on the serial port.
    while(Serial.available() >=  TIME_MSG_LEN ){  // time message consists of a header and ten ascii digits
      char c = Serial.read() ; 
      //Serial.print(c);  
      if( c == TIME_HEADER ){       
        time_t pctime = 0;
        for( i = 0; i < TIME_MSG_LEN -1; i++){   
          c = Serial.read();          
          if( c >= '0' && c <= '9'){   
            pctime = (10 * pctime) + (c - '0') ; // convert digits to a number    
          }
        }// Posix seconds since 1/1/1970 00:00:00 epoch
        #if DEBUG
          Serial.print(F("DEBUG processSyncMessage() pctime: ")); Serial.println(pctime);
        #endif
        return pctime; 
      }  
    }
    return 0;
  }  //processSyncMessage()
  
  time_t requestSync(void) {
    Serial.write(TIME_REQUEST); 
    #if DEBUG
      Serial.print(F("DEBUG1 requestSync() Serial.peek(): ")); Serial.println(Serial.peek());
    #endif
      delay(3000); // ~2120 mS required to put TIME_REQUEST in Serial buffer @ 57600
    #if DEBUG
      Serial.print(F("DEBUG2 requestSync() Serial.peek(): ")); Serial.println(Serial.peek());
    #endif
    return 0; // the time will be sent later in response to serial mesg
  }  //requestSync()
#endif 

char *formatCSV(float LPS, DateTime dt){
  // Get litres/Sec value and return CSV formatted string with timestamp
  // CVS format: UTC ISO8601 yyyy-mm-ddThh:mm:ss or yyyymmddThhmmss, rate <newline>
  // buffer = year(t) + month(t) + day(t) + "T" + hour(t) + minute(t) + second(t) + ",";
  char *CSV = "00000000T000000,000.00"; // 23 inc null
  char LPS_buffer[] = "NOTSET";

  unsigned int x;
  //uint8_t i; // global
  char A_num;
  
  #if TIME_DBG
    timeProfile = millis() - timeProfile;
    if (timeProfile >= 8000){
      Serial.print(F("TIMING formatCSV() A: ")); Serial.println(timeProfile);
    }
  #endif


  x = dt.year();
  A_num  = char((x / 1000) + 48); CSV[0] = A_num;
  A_num  = char(((x % 1000) / 100) + 48); CSV[1] = A_num;
  A_num  = char(((x % 100) / 10) + 48); CSV[2] = A_num;
  A_num  = char((x % 10) + 48); CSV[3] = A_num;

  x = dt.month();
  A_num  = char((x / 10) + 48); CSV[4] = A_num;
  A_num  = char((x % 10) + 48); CSV[5] = A_num;

  x = dt.day();
  A_num  = char((x / 10) + 48); CSV[6] = A_num;
  A_num  = char((x % 10) + 48); CSV[7] = A_num;

  x = dt.hour();
  A_num  = char((x / 10) + 48); CSV[9] = A_num;
  A_num  = char((x % 10) + 48); CSV[10] = A_num;

  x = dt.minute();
  A_num  = char((x / 10) + 48); CSV[11] = A_num;
  A_num  = char((x % 10) + 48); CSV[12] = A_num;

  x = dt.second();
  A_num  = char((x / 10) + 48); CSV[13] = A_num;
  A_num  = char((x % 10) + 48); CSV[14] = A_num;

  if (LPS > 999.99){

    #if ECHO_TO_SERIAL
      Serial.println(F("Litres per second value out of range"));
    #endif
    LPS_buffer[0] = ' ';
    LPS_buffer[1] = '>';
    LPS_buffer[2] = 'M';
    LPS_buffer[3] = 'A';
    LPS_buffer[4] = 'X';
    LPS_buffer[5] = ' ';

  }
  else{
    // dtostrf(floatVar, minStringWidthIncDecimalPoint, numVarsAfterDecimal, charBuf) 
    // avr-libc alternative to non-functioning String(float)

  #if TIME_DBG
    timeProfile = millis() - timeProfile;
    if (timeProfile >= 8000){
      Serial.print(F("TIMING formatCSV() B: ")); Serial.println(timeProfile);
    }
  #endif

    dtostrf(LPS, 6, 2, LPS_buffer);
    if (LPS < 100){
      LPS_buffer[0] = '0';
    }
    if (LPS < 10){
      LPS_buffer[1] = '0';
    }

  }
  for (i = 0; i < 6; i++) {
    CSV[i+16] = LPS_buffer[i];
  }  
  
  #if DEBUG
    Serial.print(F("DEBUG formatCSV() CSV: ")); Serial.println(CSV);
  #endif
  
  #if TIME_DBG
    timeProfile = millis() - timeProfile;
    if (timeProfile >= 8000){
      Serial.print(F("TIMING formatCSV() C: ")); Serial.println(timeProfile);
    }
  #endif


  return CSV;
}  //formatCSV()

void dateTime(uint16_t* date, uint16_t* time) { //__________________possible naming overload
  // date time callback function.
  // See SdFile::dateTimeCallback() for usage.
  // return date, time using FAT_DATE macro to format fields
  DateTime now = RTC.now();
  *date = FAT_DATE(now.year(), now.month(), now.day());
  *time = FAT_TIME(now.hour(), now.minute(), now.second());
}  //dateTime()

void initialiseSDcard(void) {
  #if DEBUG  
    Serial.print(F("DEBUG initializing SD card --> "));
  #endif
  
  pinMode(10, OUTPUT); // chipSelect
  wdt_reset(); // possibly lengthy procedure

  #if SD_CHECK
    // check for SD exist
    #if DEBUG
      Serial.print(F("DEBUG card.init(SPI_HALF_SPEED.. \n"));
    #endif

    if (!card.init(SPI_HALF_SPEED, chipSelect)) {error("\ncard.init failed");}
    if (!card.readCID(&cid)){error("readCID failed");}
    SD_serial = cid.psn;
    Serial.print(F("\nSD card serial number: ")); Serial.println(SD_serial);

    // check for SD card space
    //wdt_reset(); // lengthy procedure
    if (!vol.init(&card)) {error("\nvol.init failed");}
    Serial.print(F("SD card clusterCount: ")); Serial.println(vol.clusterCount());
    Serial.print(F("SD card freeClusters: ")); Serial.println(vol.freeClusterCount());
  #endif

  // initialize the SD card at SPI_HALF_SPEED to avoid bus errors with
  // breadboards.  use SPI_FULL_SPEED for better performance.
  //if (!sd.init(SPI_HALF_SPEED)) sd.initErrorHalt();
    // initialize the SD card
  if (!sd.begin(chipSelect,SPI_FULL_SPEED)) sd.initErrorHalt(); //______________________L
  //if (!sd.init(SPI_FULL_SPEED)) sd.initErrorHalt();
  
  #if DEBUG  
    Serial.println(F("DEBUG SD card initialized."));
  #endif
}  //initialiseSDcard()

char* logFileName(DateTime dt, unsigned int inc) {
  // inc: file increment on the day
  // buffer = file# + year(t) + month(t) + day(t)
  // format = "AAAymmdd.CSV" where "AAA" = base 26 alphabetical file ordering
  // => file time period > 20sec

  char *fname = "AAA00000.CSV"; // 13 inc null
  char A_num;
  unsigned int x;
  //uint8_t i;  //global

  inc = inc % 17576;

  A_num = char((inc / 676) + 65); fname[0] = A_num;
  A_num = char(((inc % 676) / 26) + 65); fname[1] = A_num;
  A_num = char((inc % 26) + 65); fname[2] = A_num;

  x = dt.year();
  //A_num  = char(((x % 100) / 10) + 48); fname[2] = A_num;
  A_num  = char((x % 10) + 48); fname[3] = A_num;

  x = dt.month();
  A_num  = char((x / 10) + 48); fname[4] = A_num;
  A_num  = char((x % 10) + 48); fname[5] = A_num;

  x = dt.day();
  A_num  = char((x / 10) + 48); fname[6] = A_num;
  A_num  = char((x % 10) + 48); fname[7] = A_num;

  return fname;
}  //logFileName()
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
void loop(void)
{
  unsigned int log_inc = 0;
  unsigned long mS_interval;
  char *f_name;
  char *f_csv; 
  char *f_tbc; 
  float LpS; // litres per second 

  #if RTC_SYNC
    #if ECHO_TO_SERIAL
      serialSynch();
    #endif
  #endif

  #if SD_LOG
    f_name = uniqueLogFileName();
    logfile = createLogFile(f_name); 
    logfile.println(F("Rev:0.6.0,   S.RUISLIP"));
    logfile.println(F(SENSOR_IDENTIFIER));
    logfile.println(F("temp:C,power:V,cond:mS"));
    f_tbc = formatTBC(getTemp(), getPowerVoltage(), getSiemens());
    logfile.println(f_tbc);
    logfile.println(F("yyyymmddThhmmss,dm^3/s"));
  #endif

  #if ECHO_TO_SERIAL
    Serial.print(F("Logfile created: ")); 
    Serial.println(f_name);
    Serial.println(F("Rev:0.6.0,   S.RUISLIP"));
    Serial.println(F(SENSOR_IDENTIFIER));
    Serial.println(F("yyyymmddThhmmss,dm^3/s"));
    Serial.println(f_tbc);
  #endif

  #if TIME_DBG
    timeProfile = millis();
  #endif

  while (log_inc < FILE_MAX_LOG) {

    #if DEBUG
        Serial.print(F("DEBUG--------------------->log_inc: ")); Serial.println(log_inc);
    #endif

    #if TIME_DBG
        timeProfile = millis() - timeProfile;
        //if (timeProfile >= 8000){
          Serial.print(F("TIMING 1: ")); Serial.println(timeProfile);
        //}
    #endif

    //wdt_reset();

    mS_interval = getPulseInterval();
   

    #if TIME_DBG
        timeProfile = millis() - timeProfile;
        //if (timeProfile >= 8000){
          Serial.print(F("TIMING 2: ")); Serial.println(timeProfile);
        //}
    #endif


    if (no_flow == false) {

      #if TIME_DBG
        timeProfile = millis() - timeProfile;
        //if (timeProfile >= 8000){
          Serial.print(F("TIMING 3- flow: ")); Serial.println(timeProfile);
        //}
      #endif

      LpS = mS2LpS(mS_interval);
  
      #if DEBUG
        Serial.print(F("DEBUG loop() mS_interval: ")); Serial.println(mS_interval);
        Serial.print(F("DEBUG loop() LpS: ")); Serial.println(LpS);
      #endif

      #if TIME_DBG
        timeProfile = millis() - timeProfile;
        //if (timeProfile >= 8000){
          Serial.print(F("TIMING 3A flow: ")); Serial.println(timeProfile);
        //}
      #endif

      f_csv = formatCSV(LpS, RTC.now()); // now() skewed by mS2LpS() & getPulseInterval() execution time (< 0.5 S)
  
      #if SD_LOG
        #if LED_ON
          digitalWrite(redLEDpin, HIGH); // warn writing is taking place
        #endif

      #if TIME_DBG
        timeProfile = millis() - timeProfile;
        if (timeProfile >= 8000){
          Serial.print(F("TIMING 3B flow: ")); Serial.println(timeProfile);
        }
      #endif

        logfile.println(f_csv);

      #if TIME_DBG
        timeProfile = millis() - timeProfile;
        if (timeProfile >= 8000){
          Serial.print(F("TIMING 3C flow: ")); Serial.println(timeProfile);
        }
      #endif

        #if LED_ON
          digitalWrite(redLEDpin, LOW);
        #endif
      #endif

      #if ECHO_TO_SERIAL
          Serial.println(f_csv);
      #endif

      still_no_flow = 0;
    } else {
      #if TIME_DBG
      Serial.print(F("TIMING 3 NO-flow appear "));
        timeProfile = millis() - timeProfile;
        if (timeProfile >= 8000){
          Serial.print(F("TIMING 3 NO-flow: ")); Serial.println(timeProfile);
        }
      #endif

      log_inc--; 
    }  // skip a count
  
    #if TIME_DBG
      timeProfile = millis() - timeProfile;
      if (timeProfile >= 8000){
        Serial.print(F("TIMING 4 main loop, flow -> no-flow: ")); Serial.println(timeProfile);
      }
    #endif


    #if SLEEP_ON 
      if (no_flow) {
        #if DEBUG
          Serial.print(F("DEBUG loop() still_no_flow: ")); Serial.println(still_no_flow);
        #endif
        
        #if LED_ON
          digitalWrite(greenLEDpin, LOW);
          digitalWrite(redLEDpin, HIGH);
        #endif
        //By performing a sync() frequently, you can remove the SD card at any time,
        //or power off or press reset, and never lose more than a few lines of data.
        //uint32_t syncTime = 0; // time of last sync()______________________________
      
        #if SD_LOG
          wdt_reset(); // reset WDT here for sync
          logfile.sync();
        #endif
          
        #if LED_ON
          digitalWrite(redLEDpin, LOW);
        #endif
        
        if (still_no_flow < 16) {//32
          uPCsleep(8); // 4 seconds to ensure MOSFET switching, avoid until longer sleep periods
          // careful to leave WDT to 8 second reset..
          //wdt_reset();
        } else if (still_no_flow > 16) {//32
          hibernate(still_no_flow);
        } else if (still_no_flow > 180) {
          hibernate(180); // limit sleep intervals to 180 seconds (mainly to avoid human error)
        }
        
        //wdt_reset();
        #if TIME_DBG
          timeProfile = millis() - timeProfile;
          if (timeProfile >= 8000){
            Serial.print(F("TIMING 5 (no-flow/sleep): ")); Serial.println(timeProfile);
          }
        #endif

        still_no_flow += 3; 
      }
    #endif
    
    log_inc++; // increment to next line of data in CSV file

    #if TIME_DBG
      timeProfile = millis() - timeProfile;
      if (timeProfile >= 8000){
        Serial.print(F("TIMING 6(log_inc++) A: ")); Serial.println(timeProfile);
      }
    #endif
    // minimum time resolution, sleep & WDT sec reset
    uPCsleep(RESOLUTION);
    initWDT(8);
    wdt_reset();

    #if TIME_DBG
      timeProfile = millis() - timeProfile;
      if (timeProfile >= 8000){
        Serial.print(F("TIMING 6(log_inc++) B: ")); Serial.println(timeProfile);
      }
    #endif
  }

  #if SD_LOG
    logfile.close();
  
    #if ECHO_TO_SERIAL
      Serial.print(F("Logfile closed: ")); Serial.println(f_name); 
    #endif
    
    if (!fileCheck(f_name)){
      #if ECHO_TO_SERIAL
        Serial.print(F("FAILURE file length check")); 
      #endif
      while(1){} // force system reset 
    }
  #endif
  
//  #if DEBUG
//    Serial.print(F("DEBUG loop() -sleep between readings")); 
//  #endif
  
  #if TIME_DBG
      timeProfile = millis() - timeProfile;
      if (timeProfile >= 8000){
        Serial.print(F("TIMING 5(new_file) A: ")); Serial.println(timeProfile);
      }
  #endif
  wdt_reset();
}


//__TODO: create cache 512 byte buffer and flush as file append -> low risk of data loss on card removal
// current strategy to flush on no_flow timeout
//__TODO: flashing errorcodes? only for offline debugging.. prefer WDT system reset

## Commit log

2013-03-30 Gerber files for custom sensor shield & PSU
    [Cap_Shield_07 - Bill Of Materials.csv, Cap_Shield_07 - Bill Of Materials.ods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]
2013-05-03 CERN OHL added, require updated silkscreen logo

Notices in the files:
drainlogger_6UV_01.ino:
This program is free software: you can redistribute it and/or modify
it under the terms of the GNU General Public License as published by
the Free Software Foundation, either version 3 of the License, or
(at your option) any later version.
